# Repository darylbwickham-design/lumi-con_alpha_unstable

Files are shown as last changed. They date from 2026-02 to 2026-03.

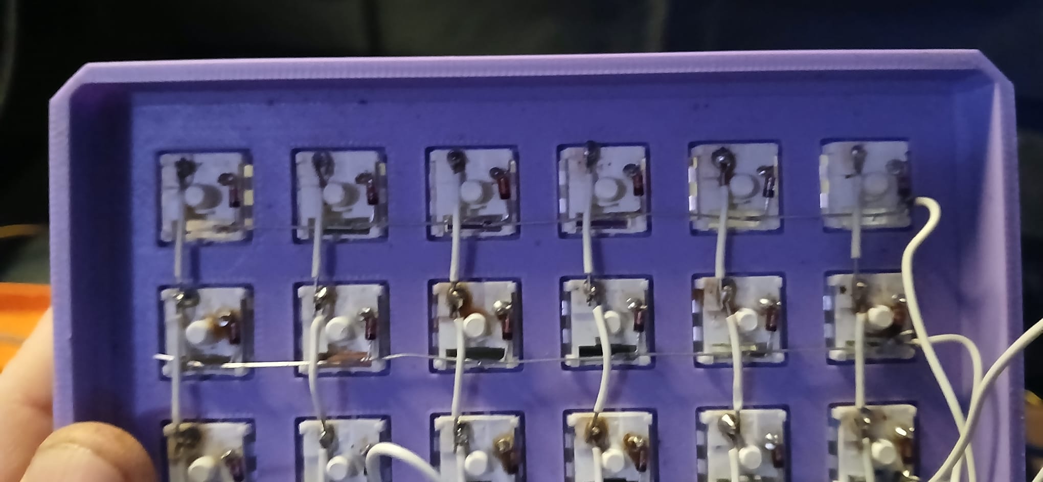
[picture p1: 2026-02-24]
Alpha/instructions/diode wiring.jpeg

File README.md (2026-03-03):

# Lumi-Con (ESP8266 + Pico) — Lumia-Based Stream Controller

Lumi-Con is an open-source, Lumia-first **control deck** built around:

- **Raspberry Pi Pico (RP2040)**: scans a key matrix (currently 6×6 test matrix)
- **ESP8266**: Wi‑Fi + HTTP + optional TFT display + relays key events to **Lumia** via a plugin

This repo/docs cover **three supported builds**:

1) **6×6 ONLY (Buttons Only)** — Pico → ESP → Lumia plugin (alerts/variations)  
2) **CHAT RELAY ONLY (TFT Chat Bridge)** — Lumia plugin → ESP TFT (display messages)  
3) **INTEGRATED (Recommended / Pro)** — same ESP firmware + integrated plugin (events + TFT actions + device status)

Important note:

- **Build 1 and Build 3 use the same ESP8266 integrated firmware.**
- Build 1 simply does **not** use TFT actions (so **ESP Base URL** can be left blank).

---

## Table of Contents

- [Hardware Overview](#hardware-overview)
- [Arduino IDE One-Time Setup](#arduino-ide-one-time-setup)
- [Wiring](#wiring)
- [Firmware Upload](#firmware-upload)
- [Plugin Build + Install (CLI)](#plugin-build--install-cli)
- [Build 1: 6×6 ONLY (Buttons Only)](#build-1-66-only-buttons-only)
- [Build 2: CHAT RELAY ONLY (TFT Chat Bridge)](#build-2-chat-relay-only-tft-chat-bridge)
- [Build 3: INTEGRATED (Recommended)](#build-3-integrated-recommended)
- [Key Labels (Short + Long)](#key-labels-short--long)
- [UI Mode: Legacy GET vs UI POST](#ui-mode-legacy-get-vs-ui-post)
- [Plugin Icon](#plugin-icon)
- [Troubleshooting](#troubleshooting)

---

## Hardware Overview

### Current test configuration

- **Pico** scans a **6×6** keypad matrix and sends packets over UART to the ESP8266.
- **ESP8266**:
  - receives UART packets on RX (GPIO3)
  - computes short/long press
  - `POST`s key events to the Lumia plugin `/event`
  - hosts TFT endpoints:
    - `GET /msg?t=...`
    - `GET /status?t=...`
    - `GET /clear`
    - `POST /ui` (optional UI JSON endpoint)
    - `GET /health` (device health JSON)

---

## Arduino IDE One-Time Setup

### 1) Install Arduino IDE

https://www.arduino.cc/en/software

### 2) Add board manager URLs

Arduino IDE → **File → Preferences** → **Additional Boards Manager URLs**  
Paste (comma-separated is fine):

- ESP8266  
  `http://arduino.esp8266.com/stable/package_esp8266com_index.json`

- Pico (Earle Philhower)  
  `https://github.com/earlephilhower/arduino-pico/releases/download/global/package_rp2040_index.json`

### 3) Install board packages

Arduino IDE → **Tools → Board → Boards Manager**  
Install:

- **ESP8266 by ESP8266 Community**
- **Raspberry Pi Pico/RP2040** (Earle Philhower)

---

## Wiring

IMPORTANT (ESP flashing):

- When uploading to the ESP8266, disconnect **Pico TX (GP0) → ESP RX (GPIO3)** or the upload may fail.

### A) Pico ↔ 6×6 Matrix (matches `6x6_test_pico.ino`)

Rows (inputs w/ pullups):

- R0 → **GP12**
- R1 → **GP1**
- R2 → **GP2**
- R3 → **GP3**
- R4 → **GP4**
- R5 → **GP5**

Cols (outputs):

- C0 → **GP6**
- C1 → **GP7**
- C2 → **GP8**
- C3 → **GP9**
- C4 → **GP10**
- C5 → **GP11**

### B) Pico → ESP8266 UART

- Pico **GP0 (TX)** → ESP **RX / GPIO3**
- Pico **GND** → ESP **GND**
- Optional but recommended: **1k resistor** in series on the TX line

### C) ESP8266 → ST7735 TFT (SPI)

Common wiring for typical ESP8266 dev boards:

- TFT **VCC**  → **3V3**
- TFT **GND**  → **GND**
- TFT **SCK**  → **D5 (GPIO14)**
- TFT **MOSI** → **D7 (GPIO13)**
- TFT **CS**   → **D2 (GPIO4)**
- TFT **DC**   → **D1 (GPIO5)**
- TFT **RST**  → **D0 (GPIO16)**

---

## Firmware Upload

### Flash the Pico (6×6 scanner)

1. Plug Pico into your PC via USB
2. Arduino IDE → select board: **Raspberry Pi Pico**
3. Open: `6x6_test_pico.ino`
4. Upload
5. Optional: Serial Monitor at **115200** to see `PRESS/RELEASE` logs

### Flash the ESP8266

1. Disconnect Pico GP0 → ESP RX (GPIO3) while uploading
2. Plug ESP8266 into PC via USB
3. Arduino IDE → select your ESP8266 board
4. Open and upload the ESP sketch you want (see builds below)
5. Reconnect Pico GP0 → ESP RX after upload

---

## Plugin Build + Install (CLI)

Open a terminal in the plugin folder (the folder containing `package.json`).

### Build (Windows)

```bash
npm install
npx lumia-plugin validate .
npx lumia-plugin build . --out .\OUTPUT_NAME.lumiaplugin
```

### Install into Lumia

- Lumia → Configuration → Plugins → Installed → Install Manually
- Select the `.lumiaplugin` you built

---

## Build 1: 6×6 ONLY (Buttons Only)

### What it does

- Pico scans keys → ESP sends events to a Lumia plugin
- Lumia plugin triggers two alerts:
  - **6×6 short**
  - **6×6 long**
- Each alert supports **36 variations** (Key `0–35`)

### Firmware used (same as Integrated)

- Pico: `6x6_test_pico.ino`
- ESP: `lumi_con_esp_integrated_0_0_4.ino` (or your current integrated firmware)

### Plugin (Lumia)

- Install: **Lumi-Con Bridge (Integrated v5.2)** (`.lumiaplugin`)
- Minimal settings (buttons only):
  - Enable Listener = **ON**
  - Listen Port = **8787**
  - Shared Secret = **(blank)**
- You can leave **ESP Base URL** blank if you are not using a TFT.

### ESP config (edit + flash)

```cpp
const char* PLUGIN_HOST = "192.168.1.87"; // your PC IP
constexpr uint16_t PLUGIN_PORT = 8787;    // same as Listen Port
const char* PLUGIN_SECRET = "";           // same as Shared Secret (or blank)
```

---

## Build 2: CHAT RELAY ONLY (TFT Chat Bridge)

### What it does

- Lumia plugin sends display text to the ESP TFT
- Uses:
  - `GET /msg?t=...`
  - `GET /clear`

### Firmware used

- ESP: `espChatBridge.ino` (hardcoded Wi‑Fi)

### ESP Wi‑Fi (edit + flash)

```cpp
const char* WIFI_SSID = "YourWiFiName";
const char* WIFI_PASS = "YourWiFiPassword";
```

### Plugin (Lumia)

- Install: `ESP8266_TFT_Chat_Bridge.lumiaplugin`
- Settings:
  - ESP Base URL = `http://<ESP_IP>`
  - Message Path = `/msg`
  - Clear Path = `/clear`

### Quick test (browser)

- `http://<ESP_IP>/msg?t=Hello%20world`
- `http://<ESP_IP>/clear`

---

## Build 3: INTEGRATED (Recommended)

### What it does

Same ESP firmware + integrated Lumia plugin:

Device → PC (plugin listener)

- `POST http://<PC_IP>:8787/event` with JSON like `{ "event": 0..71 }`

Plugin → device (TFT actions)

- Display Add Line → `/msg` (Legacy GET) or `/ui` (UI POST)
- Display Set Status → `/status` (Legacy GET) or `/ui` (UI POST)
- Display Clear → `/clear` (Legacy GET) or `/ui` (UI POST)

Integrated plugins can also add:

- device connected/offline state
- device status variables (device id, last seen, RSSI, etc.)
- optional debug toasts

### Firmware used

- Pico: `6x6_test_pico.ino`
- ESP: `lumi_con_esp_integrated_0_0_4.ino` (or your current integrated firmware)

### Plugin (Lumia)

- Install: **Lumi-Con Bridge (Integrated v5.2)** (`.lumiaplugin`)

Minimal settings:

- Enable Listener = **ON**
- Listen Port = **8787**
- Shared Secret = **(blank)**

Optional (for TFT actions):

- ESP Base URL = `http://<ESP_IP>`

Optional (if you set a secret):

- Shared Secret must match what the ESP sends.

### ESP first-time Wi‑Fi (WiFiManager)

1. Power ESP → Wi‑Fi AP appears: `Lumi-Con-Setup`
2. Connect to `Lumi-Con-Setup`
3. Open: `http://192.168.4.1`
4. Select home Wi‑Fi + password → Save
5. ESP reboots → TFT shows IP

### ESP firmware config (edit + flash)

```cpp
const char* PLUGIN_HOST = "192.168.1.87"; // your PC IP
constexpr uint16_t PLUGIN_PORT = 8787;    // same as plugin Listen Port
const char* PLUGIN_SECRET = "";           // same as plugin Shared Secret (or blank)
```

---

## Key Labels (Short + Long)

Integrated plugins that support key maps provide:

- Key labels (Short 0–35): 36 lines, one label per key
- Key labels (Long 0–35): 36 lines, one label per key

The plugin exposes `key_label` and automatically picks the correct list based on short/long press.

---

## UI Mode: Legacy GET vs UI POST

This affects **TFT display only** (not key presses).

### Legacy GET (simple)

Plugin sends:

- `GET http://<ESP_IP>/msg?t=...`
- `GET http://<ESP_IP>/status?t=...`
- `GET http://<ESP_IP>/clear`

### UI POST (JSON)

Plugin sends:

- `POST http://<ESP_IP>/ui`

Example payloads:

- `{"channel":"status","text":"..."}`
- `{"channel":"chat","text":"..."}`
- `{"channel":"clear"}`

### Quick UI POST test (Windows PowerShell)

```powershell
curl -X POST "http://<ESP_IP>/ui" -H "Content-Type: application/json" -d "{\"channel\":\"status\",\"text\":\"OK: Connected\"}"
curl -X POST "http://<ESP_IP>/ui" -H "Content-Type: application/json" -d "{\"channel\":\"chat\",\"text\":\"Hello\"}"
curl -X POST "http://<ESP_IP>/ui" -H "Content-Type: application/json" -d "{\"channel\":\"clear\"}"
```

---

## Plugin Icon

1) Put your icon file in the plugin folder (same folder as `manifest.json`)  
Recommended name: `icon.png`

2) Edit `manifest.json` (top-level, near id/name/version) and add:

```json
"icon": "./icon.png"
```

3) Rebuild:

```bash
npm install
npx lumia-plugin validate .
npx lumia-plugin build . --out .\YOUR_OUTPUT_NAME.lumiaplugin
```

Notes:

- PNG square icons work best (256×256 recommended)
- If validate fails, double-check the icon path matches the filename exactly

---

## Troubleshooting

### ESP upload fails

- Disconnect **Pico GP0 (TX) → ESP RX (GPIO3)** during ESP flashing.

### TFT is white / blank

Try these in order:

1) Change ST7735 tab in code  
`INITR_GREENTAB` → `INITR_REDTAB` or `INITR_BLACKTAB`

2) RST on D0 can be flaky  
Wire TFT RST → ESP RST and set RST pin to `-1` in the constructor if needed.

### Lumia alerts don’t fire

- Confirm ESP `PLUGIN_HOST` is your **PC IP**
- Confirm ESP `PLUGIN_PORT` matches plugin **Listen Port**
- If using Shared Secret, both ends must match exactly
- Make sure PC and ESP are on the same LAN

### TFT message actions don’t work

- Confirm plugin setting **ESP Base URL** is correct:
  - must be `http://<ESP_IP>` (no trailing slash)
- Confirm ESP endpoints work in browser:
  - `/msg?t=Hello`
  - `/status?t=OK`
  - `/clear`

### Device health endpoints

- ESP health: `http://<ESP_IP>/health`
- Plugin health (listener): `http://<PC_IP>:8787/health`

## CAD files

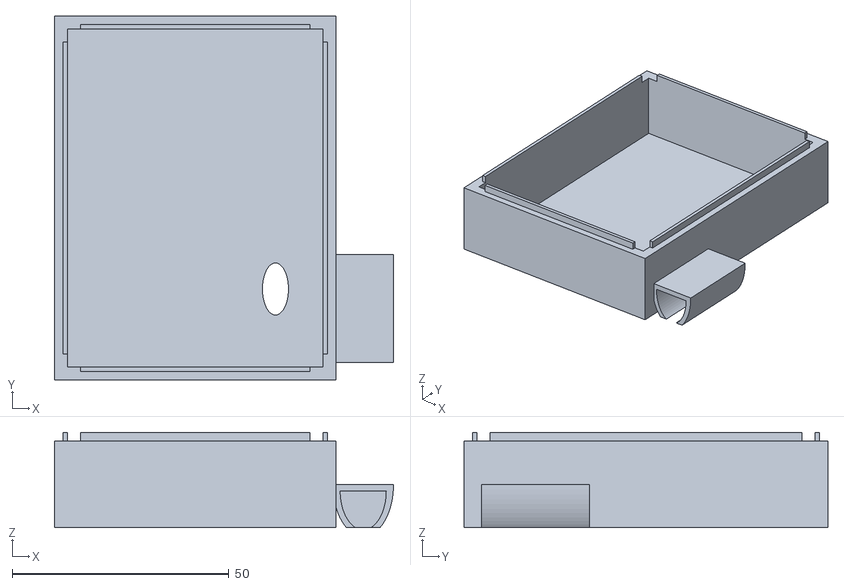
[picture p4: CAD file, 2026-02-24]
Alpha/3d files/left 3x4 rear.stl
78.2 x 84.0 x 22.0

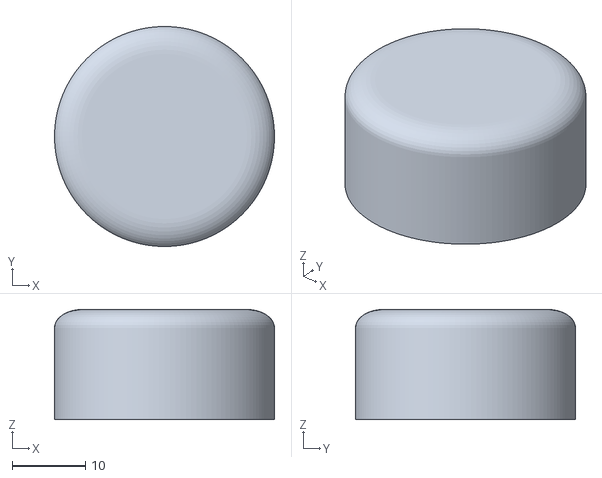
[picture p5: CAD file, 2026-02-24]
Alpha/3d files/rotary dial.stl
30.0 x 30.0 x 15.0

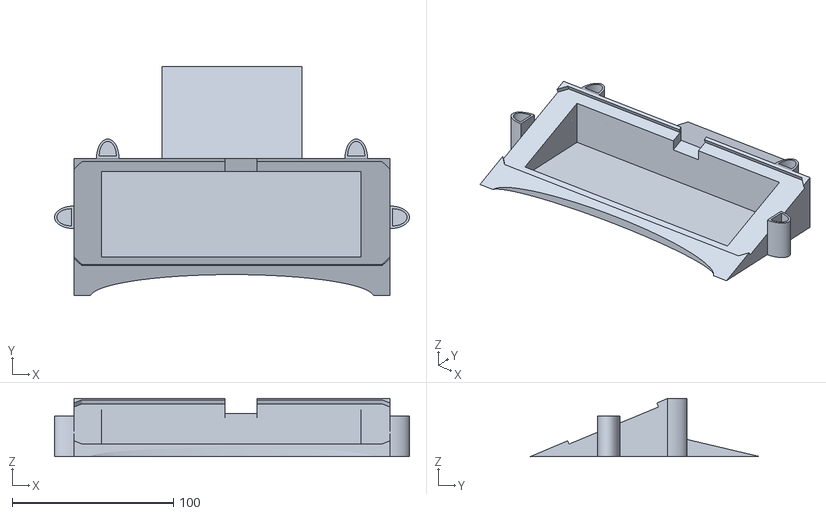
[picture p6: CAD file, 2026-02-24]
Alpha/3d files/Base.stl
220.0 x 142.0 x 36.0

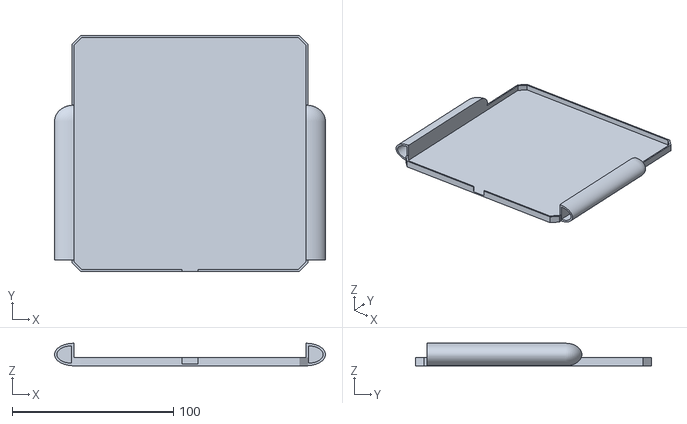
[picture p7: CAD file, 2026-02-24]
Alpha/3d files/6X6 Rear.stl
168.0 x 146.0 x 14.0

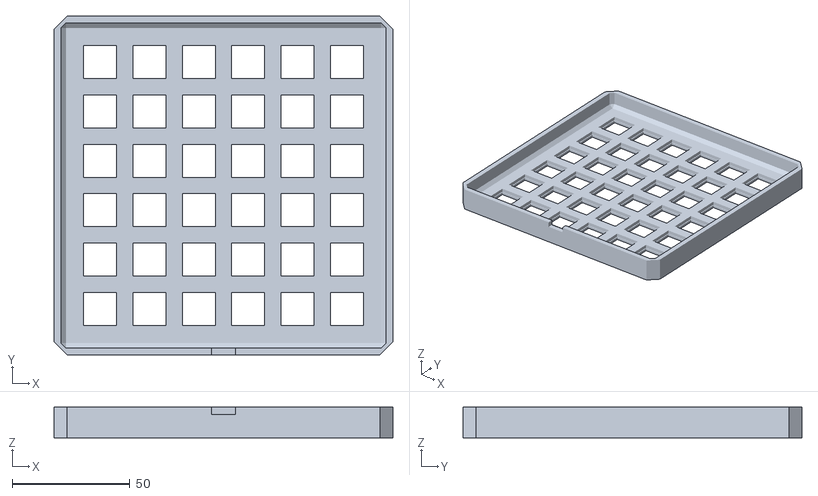
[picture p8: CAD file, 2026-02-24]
Alpha/3d files/6X6 Front.stl
144.0 x 144.0 x 13.0

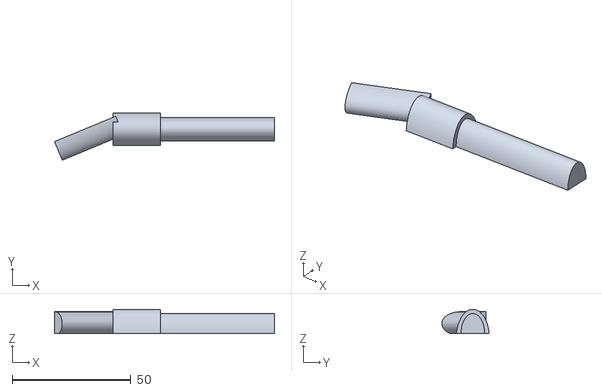
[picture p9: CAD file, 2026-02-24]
Alpha/3d files/connector.stl
92.7 x 20.0 x 10.2

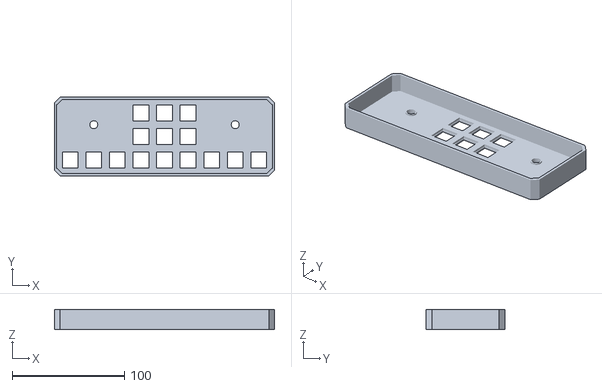
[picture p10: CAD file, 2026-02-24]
Alpha/3d files/Base Front Panel.stl
196.0 x 70.0 x 18.0

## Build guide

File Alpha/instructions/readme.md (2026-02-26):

# Lumi-Con (ESP8266 + Pico) — Lumia-Based Stream Controller

Lumi-Con is an open-source, Lumia-first “stream deck” style controller built around:
- **Raspberry Pi Pico (RP2040)**: scans a key matrix (currently 6×6 test matrix)
- **ESP8266**: Wi-Fi + HTTP + TFT display + relays key events to Lumia via a plugin

This repo/docs cover **three supported builds**:

1) **6×6 ONLY (Matrix Relay)**  
   Pico → ESP → Lumia plugin (alerts/variations)

2) **CHAT RELAY ONLY (TFT Chat Bridge)**  
   Lumia plugin → ESP TFT (display messages)

3) **INTEGRATED (Recommended)**  
   One ESP firmware + one plugin (events + TFT actions)

---

## Table of Contents
- [Hardware Overview](#hardware-overview)
- [Arduino IDE One-Time Setup](#arduino-ide-one-time-setup)
- [Wiring](#wiring)
- [Firmware Upload](#firmware-upload)
  - [Flash the Pico (6×6 scanner)](#flash-the-pico-66-scanner)
  - [Flash the ESP8266](#flash-the-esp8266)
- [Plugin Build + Install](#plugin-build--install)
- [Build 1: 6×6 ONLY (Matrix Relay)](#build-1-66-only-matrix-relay)
- [Build 2: CHAT RELAY ONLY (TFT Chat Bridge)](#build-2-chat-relay-only-tft-chat-bridge)
- [Build 3: INTEGRATED (Recommended)](#build-3-integrated-recommended)
- [Plugin Icon](#plugin-icon)
- [Troubleshooting](#troubleshooting)

---

## Hardware Overview

### Current test configuration
- **Pico** scans a **6×6** keypad matrix and sends packets over UART to the ESP8266.
- **ESP8266**:
  - receives UART packets on RX
  - computes short/long press
  - `POST`s key events to the Lumia plugin `/event`
  - hosts TFT endpoints:
    - `GET /msg?t=...`
    - `GET /status?t=...`
    - `GET /clear`
    - optional: `POST /ui` (future UI hook)

---

## Arduino IDE One-Time Setup

### 1) Install Arduino IDE
https://www.arduino.cc/en/software

### 2) Add board manager URLs
Arduino IDE → **File → Preferences** → **Additional Boards Manager URLs**  
Paste (comma-separated is fine):

- ESP8266:
  - `http://arduino.esp8266.com/stable/package_esp8266com_index.json`
- Pico (Earle Philhower):
  - `https://github.com/earlephilhower/arduino-pico/releases/download/global/package_rp2040_index.json`

### 3) Install board packages
Arduino IDE → **Tools → Board → Boards Manager**  
Install:
- **ESP8266 by ESP8266 Community**
- **Raspberry Pi Pico/RP2040** (Earle Philhower)

---

## Wiring

> **IMPORTANT (ESP flashing):** When uploading to the ESP8266, disconnect **Pico TX (GP0) → ESP RX (GPIO3)** or the upload may fail.

### A) Pico ↔ 6×6 Matrix (matches `6x6_test_pico.ino`)
**Rows** (inputs w/ pullups):
- R0 → **GP12**
- R1 → **GP1**
- R2 → **GP2**
- R3 → **GP3**
- R4 → **GP4**
- R5 → **GP5**

**Cols** (outputs):
- C0 → **GP6**
- C1 → **GP7**
- C2 → **GP8**
- C3 → **GP9**
- C4 → **GP10**
- C5 → **GP11**

### B) Pico → ESP8266 UART
- Pico **GP0 (TX)** → ESP **RX / GPIO3**
- Pico **GND** → ESP **GND**
- (Optional but recommended) **1k resistor** in series on the TX line

### C) ESP8266 → ST7735 TFT (SPI)
Common wiring for NodeMCU / Wemos D1 mini style ESP8266:

- TFT **VCC**  → **3V3**
- TFT **GND**  → **GND**
- TFT **SCK**  → **D5 (GPIO14)**
- TFT **MOSI** → **D7 (GPIO13)**
- TFT **CS**   → **D2 (GPIO4)**
- TFT **DC**   → **D1 (GPIO5)**
- TFT **RST**  → **D0 (GPIO16)**

**If the TFT is white:** see [Troubleshooting](#troubleshooting).

---

## Firmware Upload

### Flash the Pico (6×6 scanner)
1. Plug Pico into your PC via USB
2. Arduino IDE → select board: **Raspberry Pi Pico**
3. Open: `6x6_test_pico.ino`
4. Upload
5. Optional: Serial Monitor at **115200** to see `PRESS/RELEASE` logs

### Flash the ESP8266
1. **Disconnect** Pico GP0 → ESP RX (GPIO3) while uploading
2. Plug ESP8266 into PC via USB
3. Arduino IDE → select your ESP8266 board (NodeMCU / Wemos D1 mini / etc.)
4. Open and upload the ESP sketch you want (see build sections below)
5. Reconnect Pico GP0 → ESP RX after upload

---

## Plugin Build + Install

### Build (CLI)
Open a terminal in the plugin folder (the folder containing `package.json`):

```bash
npm install
npx lumia-plugin validate .
npx lumia-plugin build . --out .\OUTPUT_NAME.lumiaplugin

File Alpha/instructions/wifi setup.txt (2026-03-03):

============================================================
LUMI-CON SETUP NOTES (COPY/PASTE)
============================================================

-----------------------------
1) 6x6 ONLY (Buttons Only)
-----------------------------

LUMIA (PC) - PLUGIN SETTINGS
- Install/Enable plugin: Lumi-Con Bridge (Integrated v5.2)
- Enable Listener: ON
- Listen Port: 8787
- Shared Secret: (leave blank) OR set a value
- ESP Base URL: (leave blank if you are not using a TFT)

ESP (DEVICE) - FIRMWARE SETTINGS (edit + flash)
Set these to match Lumia plugin + your PC IP:

const char* PLUGIN_HOST = "192.168.1.87"; // your PC IP
constexpr uint16_t PLUGIN_PORT = 8787;    // same as Listen Port
const char* PLUGIN_SECRET = "";           // same as Shared Secret (or blank)

WHAT SHOULD HAPPEN
- Press keys -> ESP POSTs to: http://PC_IP:8787/event
- Lumia triggers short/long alerts with variations

-----------------------------
2) CHAT RELAY ONLY (TFT Chat Bridge)
-----------------------------

ESP (DEVICE) - WIFI SETUP (hardcoded sketch: espChatBridge.ino)
Edit + flash:

const char* WIFI_SSID = "YourWiFiName";
const char* WIFI_PASS = "YourWiFiPassword";

LUMIA (PC) - PLUGIN SETTINGS
- Install/Enable plugin: ESP8266_TFT_Chat_Bridge
- ESP Base URL: http://<ESP_IP>     (ESP IP shows on TFT)
- Message Path: /msg
- Clear Path: /clear

QUICK TEST (browser)
- http://<ESP_IP>/msg?t=Hello%20world
- http://<ESP_IP>/clear

-----------------------------
3) INTEGRATED (Buttons + TFT)

NOTE: Build 1 and Build 3 use the same ESP8266 integrated firmware.
-----------------------------

ESP (DEVICE) - FIRST TIME WIFI (WiFiManager build)
1) Power ESP -> it creates Wi-Fi AP: Lumi-Con-Setup
2) Connect phone/PC to Lumi-Con-Setup
3) Open: http://192.168.4.1
4) Select home Wi-Fi + enter password -> Save
5) ESP reboots -> TFT shows: IP: x.x.x.x

LUMIA (PC) - PLUGIN SETTINGS (INTEGRATED PLUGIN)
- Install/Enable plugin: Lumi-Con Bridge (Integrated v5.2)
- Enable Listener: ON
- Listen Port: 8787
- Shared Secret: (leave blank) OR set a value
- ESP Base URL: http://<ESP_IP>
- UI Mode: legacy_get  (recommended)

ESP (DEVICE) - FIRMWARE SETTINGS (edit + flash)
Set these to match Lumia plugin + your PC IP:

const char* PLUGIN_HOST = "192.168.1.87"; // your PC IP
constexpr uint16_t PLUGIN_PORT = 8787;    // same as Listen Port
const char* PLUGIN_SECRET = "";           // same as Shared Secret (or blank)

ENDPOINTS USED (FYI)
- Events (ESP -> PC plugin): POST http://<PC_IP>:8787/event   body: {"event":0..71}
- Screen (plugin -> ESP):
  - GET http://<ESP_IP>/msg?t=...
  - GET http://<ESP_IP>/status?t=...
  - GET http://<ESP_IP>/clear

WHAT SHOULD HAPPEN
- Press keys -> Lumia alerts trigger (same as old 6x6 plugin)
- Plugin actions can send text to the TFT (/msg, /status, /clear)

============================================================

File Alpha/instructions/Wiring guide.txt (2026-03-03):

LUMI-CON WIRING GUIDE (Quick Reference)

The wiring below is for the integrated build, but it also works for “6×6 only”.
- If building **Chat Bridge only**, leave out all references to the Pico.
- If building **6×6 only**, leave out all references to the TFT screen.
If in doubt, refer to the `.ino` files.

PARTS
-----
- ESP8266 (NodeMCU / Wemos D1 mini style)
- Raspberry Pi Pico (RP2040)
- 6x6 keyboard matrix (12 wires: R0..R5, C0..C5)
- ST7735 1.8" TFT (SPI)

1) PICO <-> 6x6 MATRIX (matches pico sketch)
-----------------------------------

SEE INCLUDED IMAGES FOR DIODE WIRING

MATRIX ROWS -> PICO (INPUT_PULLUP)
R0 -> GP12
R1 -> GP1
R2 -> GP2
R3 -> GP3
R4 -> GP4
R5 -> GP5

MATRIX COLS -> PICO (OUTPUT)
C0 -> GP6
C1 -> GP7
C2 -> GP8
C3 -> GP9
C4 -> GP10
C5 -> GP11

2) PICO -> ESP8266 (UART link)
-----------------------------------

Pico GP0 (UART TX) -> ESP RX / GPIO3
Pico GND           -> ESP GND

(Optional, recommended: 1k resistor in series on the TX line)

3) ESP8266 <-> ST7735 TFT (matches esp sketch)
-----------------------------------

TFT VCC -> ESP 3V3
TFT GND -> ESP GND

TFT SCK/SCL/CLK -> ESP D5 (GPIO14)
TFT MOSI/SDA/DIN -> ESP D7 (GPIO13)

TFT CS  -> ESP D2 (GPIO4)
TFT DC  -> ESP D1 (GPIO5)
TFT RST -> ESP D0 (GPIO16)

NOTES (if TFT shows white screen)
---------------------------------
- Try a different ST7735 tab constant in code:
  INITR_GREENTAB / INITR_REDTAB / INITR_BLACKTAB
- If RST on D0 is flaky:
  Wire TFT RST -> ESP RST and set TFT_RST = -1 in code.

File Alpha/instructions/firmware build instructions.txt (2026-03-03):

========================================
Lumi-Con Plugin Build Commands
========================================

PREREQS (one-time)
- Install Node.js (LTS)
- Open a terminal in the plugin folder (the folder containing package.json)

----------------------------------------
A) INTEGRATED v5.2 (used for 6×6 ONLY and INTEGRATED)
----------------------------------------

cd <PATH_TO_PLUGIN_FOLDER>
npm install
npx lumia-plugin validate .
npx lumia-plugin build . --out .\lumi_con_bridge_integrated_v5_2.lumiaplugin

----------------------------------------
B) TFT CHAT ONLY (ESP8266_TFT_Chat_Bridge)
----------------------------------------

cd <PATH_TO_PLUGIN_FOLDER>
npm install
npx lumia-plugin validate .
npx lumia-plugin build . --out .\ESP8266_TFT_Chat_Bridge.lumiaplugin

----------------------------------------
C) (Same as A)

Use the same integrated plugin build for both “6×6 only” and “Integrated”.
----------------------------------------

cd <PATH_TO_PLUGIN_FOLDER>
npm install
npx lumia-plugin validate .
npx lumia-plugin build . --out .\lumi_con_bridge_integrated_v5_2.lumiaplugin

----------------------------------------
NOTES
----------------------------------------
- <PATH_TO_PLUGIN_FOLDER> is the folder containing manifest.json + main.js + package.json.
- Output filename can be anything, but keep it ending in .lumiaplugin.
- After building, install in Lumia: Configuration -> Plugins -> Install Manually (select the .lumiaplugin).
========================================

========================================
Linux/Mac OS users
========================================

npx lumia-plugin build . --out ./lumi_con_bridge_integrated_v5_2.lumiaplugin
npx lumia-plugin build . --out ./ESP8266_TFT_Chat_Bridge.lumiaplugin
npx lumia-plugin build . --out ./lumi_con_bridge_integrated_v5_2.lumiaplugin

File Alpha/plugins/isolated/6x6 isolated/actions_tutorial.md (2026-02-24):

---
## Matrix Relay (6x6 Ver) — Actions / Variations

This plugin does not add manual actions.

Instead, configure actions on **Alert Variations**:

### Alerts created by this plugin
- **6x6 short**
- **6x6 long**

Each alert has a variation condition:
- **Which Key (0–35)**

### How to set it up in Lumia
1) Go to **Alerts → Matrix Relay (6x6 Ver) → 6x6 short**
2) Enable **Only Variations** (base alert is disabled by the plugin)
3) Click **Add Variation**
   - Condition: *Which Key (0–35)*
   - Value: pick *Key 0* (or whatever key you want)
4) Add the Lumia actions you want for that key
5) Repeat for Key 1..Key 35
6) Do the same for **6x6 long**

### Notes
- Short press triggers **6x6 short**
- Long press triggers **6x6 long**
- The variation matching uses `dynamic.value` (string) internally, so Key values are matched as text ("0".."35").
---

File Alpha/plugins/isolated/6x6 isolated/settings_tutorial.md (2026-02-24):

---
## Matrix Relay (6x6 Ver) — Settings

### 1) Listen Port
- Default is **8787**
- Your ESP8266 should POST to:

`http://<PC-IP>:<PORT>/event`

Example (with your IP):
`http://192.168.1.87:8787/event`

### 2) Shared Secret (optional)
If you set a secret here, your ESP8266 must include this HTTP header:

`X-Matrix-Secret: <your secret>`

### 3) Data format
The plugin expects JSON:

`{ "event": N }`

Where:
- Short press: **0..35**
- Long press: **36..71**

The plugin converts these into:
- **6x6 short** with key **0..35**
- **6x6 long** with key **0..35**
---

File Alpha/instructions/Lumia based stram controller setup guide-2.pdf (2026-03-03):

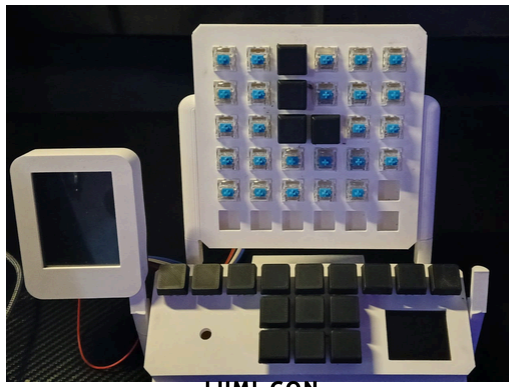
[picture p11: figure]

L U M I -C O N

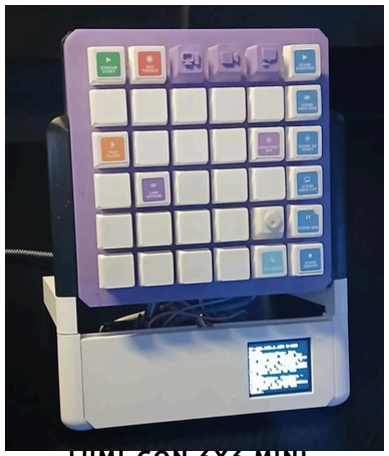
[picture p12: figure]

L U M I -C O N 6 X 6 M I N I

# L U M I A B A S E D ST R A M C O NT R O L L E R S E T U P G U I D E

### PA RT S R E Q U I R E D

- E S P 8 2 6 6
- R A S P B E R RY P I P IC O
- 3 6 × 1 N 4 1 4 8 D I O D E S
- 3 6 × M E C H A N IC A L SWITC H E S
- 1 . 8 " R G B T FT ST 7 7 3 5 ( O N LY I F Y O U WA NT C H AT /SC R E E N F E AT U R E S )

### F I L E S R E Q U I R E D

E S P 8 2 6 6 | F I R MWA R E | ( I NT E G R AT E D
F I R MWA R E ) :
- L U M I _C O N _ E S P _ I NT E G R AT E D _ 0 _ 0 _ 4

P IC O F I R MWA R E ( 6 × 6 SC A N N E R ) :
- 6 X 6 _T E ST _ P IC O

L U M I A P L U G I N ( P IC K O N E )
A ) J U ST C H AT (SC R E E N O N LY )
- E S P 8 2 6 6 -T FT -C H AT - B R I D G E B ) J U ST 6 × 6 ( B UT T O N S O N LY )
- P L U G I N V E R S I O N 5 . 2
C ) B O T H ( B UT T O N S + SC R E E N )
- P L U G I N V E R S I O N 5 . 2

# O V E R V I EW:

### WH AT T H IS IS

T H IS G U I D E C O V E R S S E T T I N G U P A L U M I -C O N C O NT R O L L E R U S I N G :
- E S P 8 2 6 6 (WI - F I + L U M I A + O PT I O N A L T FT SC R E E N )
- R A S P B E R RY P I P IC O (SC A N S T H E 6 × 6 K E Y PA D M AT R I X )
- O PT I O N A L : 1 . 8 " ST 7 7 3 5 T FT SC R E E N F O R C H AT /STAT U S D IS P L AY

## I M P O RTA NT : P IC K Y O U R P L U G I N N OW. IT C H A N G E S WH AT ST E PS

Y O U N E E D L AT E R .

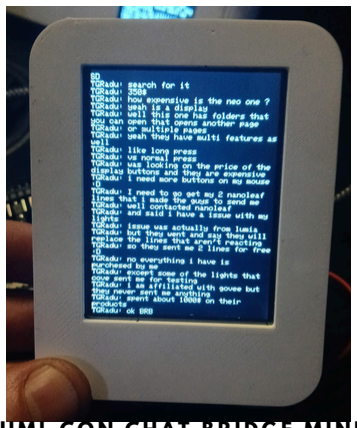
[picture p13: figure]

L U M I -C O N C H AT B R I D G E M I N I

ST E P 1 : I N STA L L A R D U I N O I D E
D OWN L O A D A R D U I N O I D E F R O M A R D U I N O ’ S WE BS IT E A N D O P E N IT.

ST E P 2 : A D D B O A R D M A N A G E R U R L S
A R D U I N O I D E → | F I L E → | P R E F E R E N C E S
A D D T H E U R L (S ) F R O M Y O U R “ B O A R D M A N A G E R U R L ” T E XT F I L E I NT O
“ A D D IT I O N A L B O A R D S M A N A G E R U R L S ”

ST E P 3 : I N STA L L B O A R D PAC K A G E S
A R D U I N O I D E → | T O O L S → | B O A R D →
B O A R D S M A N A G E R
I N STA L L :
- R A S P B E R RY P I P IC O / R P 2 0 4 0 B O A R D PAC K A G E
- E S P 8 2 6 6 B O A R D PAC K A G E

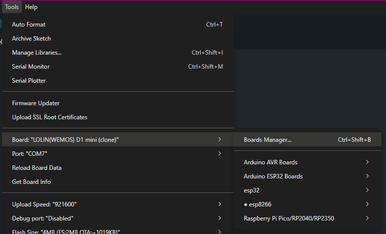
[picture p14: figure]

ST E P 4 : F L A S H T H E P IC O ( 6 × 6 SC A N N E R )
1 . P L U G T H E P IC O I NT O Y O U R PC WIT H U S B 2 . O P E N T H E 6 X 6 _T E ST _ P IC O S K E TC H I N
A R D U I N O I D E
3 . C L IC K U P L O A D
4 . O P E N S E R I A L M O N IT O R
5 . P R E SS K E YS O N Y O U R K E Y PA D
6 . Y O U S H O U L D S E E C O N F I R M AT I O N
M E SS A G E S A P P E A R I N S E R I A L M O N IT O R .

ST E P 5 : F L A S H T H E E S P 8 2 6 6 (WI - F I + L U M I A + O PT I O N A L T FT )
I M P O RTA NT : D U R I N G E S P F L A S H I N G ,
D ISC O N N E C T T H E E S P R X P I N F R O M T H E
P IC O .
( I F R X IS C O N N E C T E D , U P L O A D I N G C A N FA I L . )
1 . P L U G E S P 8 2 6 6 I NT O U S B
2 . O P E N L U M I _C O N _ E S P _ I NT E G R AT E D I N
A R D U I N O I D E
3 . C L IC K U P L O A D
4 . WH E N T H E E S P S UC C E SS F U L LY R E C E IV E S A B UT T O N P R E SS , T H E E S P ’ S O N - B O A R D L E D S H O U L D F L A S H .
A FT E R F L A S H I N G IS C O M P L E T E : R E C O N N E C T T H E P IC O → E S P R X WI R E I F Y O U A R E U S I N G T H E 6 × 6 B UT T O N S .

# F I R MWA R E F L A S H I N G :

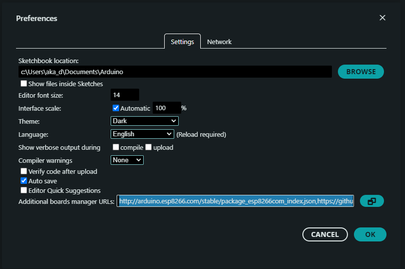
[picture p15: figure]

S T E P 2

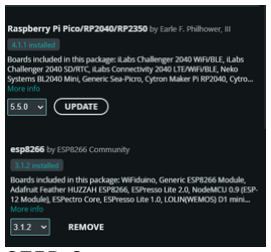
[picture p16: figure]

S T E P 3

ST E P 3

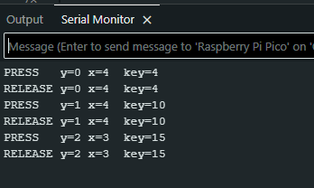
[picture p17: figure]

P IC O E X P E C T E D S E R I A L O UT P UT

ST E P 1 : C R E AT E A P L U G I N B U I L D F O L D E R
1 . M A K E A N EW F O L D E R A NYWH E R E
( D E S KT O P IS F I N E )
2 . N A M E IT S O M E T H I N G O BV I O U S ( E X A M P L E : L U M I _ P L U G I N _ B U I L D )
3 . C O PY T H E P L U G I N F I L E S Y O U WA NT T O
U S E I NT O T H IS F O L D E R

ST E P 2 : O P E N C O M M A N D P R O M PT I N T H AT F O L D E R
I N F I L E E X P L O R E R , C L IC K T H E A D D R E SS
B A R , T Y P E :
C M D
P R E SS E NT E R . A C O M M A N D P R O M PT O P E N S I N T H AT F O L D E R .

ST E P 3 : B U I L D T H E P L U G I N
R U N T H E S E C O M M A N D S :

N P M I N STA L L
N P X L U M I A - P L U G I N VA L I D AT E .
N P X L U M I A - P L U G I N B U I L D . - - O UT .
\ L U M I _C O N _ B R I D G E _ I NT E G R AT E D _V 5 _ 2 . L U M I A P L U G I N

R E N A M E
“ L U M I _C O N _ B R I D G E _ I NT E G R AT E D _V 5 _ 2 ” T O WH AT E V E R Y O U WA NT T H E O UT P UT F I L E T O B E C A L L E D .

ST E P 4 : I N STA L L I NT O L U M I A
I N L U M I A :
C O N F I G U R AT I O N → | P L U G I N S → | I N STA L L E D
→ | I N STA L L M A N U A L LY
D R A G I N ( O R S E L E C T ) T H E . L U M I A P L U G I N F I L E Y O U J U ST C R E AT E D .

# P L U G I N B U I L D A N D I N S T A L L

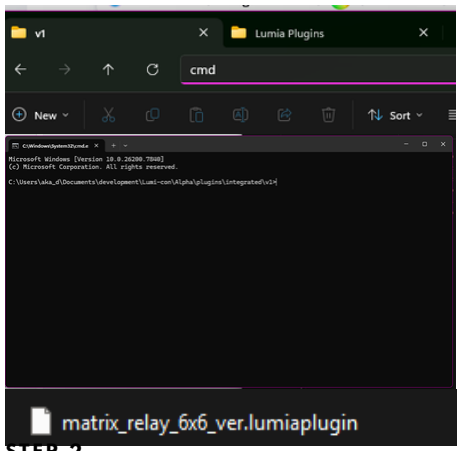
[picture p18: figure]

ST E P 2

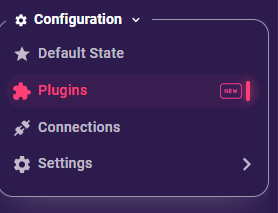
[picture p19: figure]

ST E P 4

ST E P 4

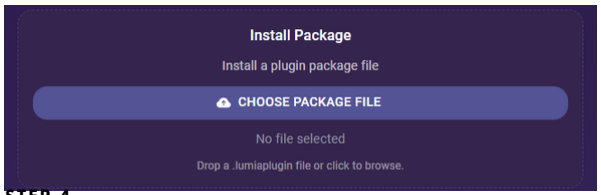
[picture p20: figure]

ST E P 4

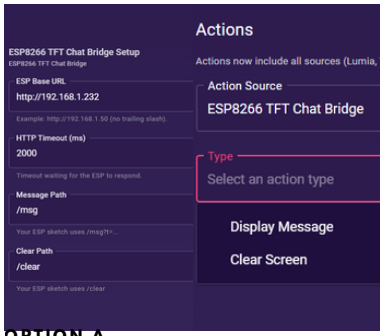
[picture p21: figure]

O PT I O N A

### A ) I F Y O U C H O S E “ J U ST C H AT ” ( E S P 8 2 6 6 -T FT -C H AT - B R I D G E )

1 . O P E N T H E P L U G I N ’ S S E T T I N G S I N L U M I A . 2 . A FT E R WI - F I C O N N E C T S , Y O U R E S P 8 2 6 6 WI L L S H OW IT S I P A D D R E SS O N T H E T FT. 3 . E NT E R T H AT I P A D D R E SS I NT O T H E
P L U G I N ’ S “ E S P B A S E U R L ” / “ D E V IC E I P ” F I E L D (WH IC H E V E R Y O U R P L U G I N
S H OWS ) .
4 . C L IC K S AV E .
5 . Y O U S H O U L D N OW S E E T H E D IS P L AY
AC T I O N S ( F O R E X A M P L E : A D D L I N E / S E T STAT U S / C L E A R ) , A N D L U M I A S H O U L D B E A B L E T O U P D AT E T H E SC R E E N .

### B ) I F Y O U C H O S E “ J U ST 6 × 6 ” ( 6 X 6 IS O L AT E D )

1 . O P E N T H E P L U G I N ’ S S E T T I N G S I N L U M I A . 2 . C L IC K S AV E .
3 . Y O U S H O U L D N OW S E E T H E 6 × 6 A L E RT S A P P E A R (T Y P IC A L LY “ 6 × 6 S H O RT ” A N D “ 6 × 6 L O N G ” ) .
4 . U S E VA R I AT I O N S ( K E Y 0 – 3 5 ) T O S E T
D I F F E R E NT AC T I O N S P E R B UT T O N .

### C ) I F Y O U C H O S E “ B O T H ” ( L U M I -C O N B R I D G E I NT E G R AT E D V 5 . 2 )

1 . O P E N T H E I NT E G R AT E D P L U G I N ’ S
S E T T I N G S I N L U M I A .
2 . M A K E S U R E “ E N A B L E L IST E N E R ” IS O N
(T H IS R E C E IV E S B UT T O N E V E NT S ) .
3 . E NT E R T H E E S P 8 2 6 6 I P A D D R E SS (S H OWN O N T H E T FT A FT E R WI - F I C O N N E C T S ) I NT O “ E S P B A S E U R L ” (T H IS E N A B L E S SC R E E N AC T I O N S ) .
4 . C L IC K S AV E .
5 . Y O U S H O U L D N OW S E E :
6 . • A L E RT S : 6 × 6 S H O RT + 6 × 6 L O N G ( F O R B UT T O N S )
7 . • AC T I O N S : D IS P L AY A D D L I N E /
D IS P L AY S E T STAT U S / D IS P L AY C L E A R
( F O R T FT )

### F I N A L C H E C K ( A L L B U I L D S )

A FT E R Y O U C L IC K S AV E :
- A L E RT S A N D / O R AC T I O N S S H O U L D
A P P E A R I N L U M I A F O R Y O U R C H O S E N
P L U G I N .
I F N O T H I N G A P P E A R S : D O U B L E C H E C K Y O U I N STA L L E D T H E C O R R E C T P L U G I N , T H E N
R E O P E N T H E P L U G I N S E T T I N G S A N D C L IC K S AV E A G A I N .

# P L U G I N C O N F I G

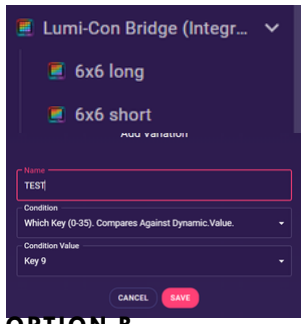
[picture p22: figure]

O PT I O N B

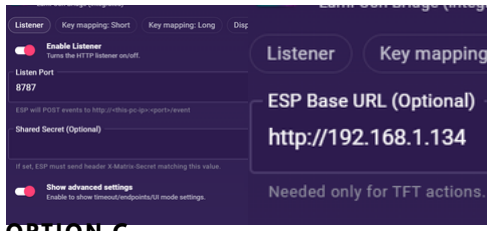
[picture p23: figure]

O PT I O N C

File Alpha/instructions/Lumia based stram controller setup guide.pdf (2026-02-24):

# L U M I A B A S E D ST R A M C O NT R O L L E R S E T U P G U I D E

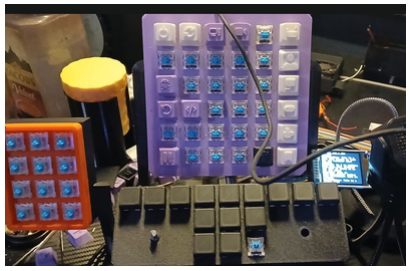
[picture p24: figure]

## PA RT S R E Q U I R E D :

E S P 8 2 6 6
P IC O P I
3 6 O F 1 N 4 1 4 8 S I G N A L D I O D E S 3 6 O F M E C H A N IC L K E YS
1 . 8 " R G B L C D T FT ST 7 7 3 5

## F I L E S R E Q U I R E D :

E S P 8 2 6 6 :
L U M I _C O N _ E S P _ I N E T R A G E D _ 0 _ 0 _ 1 P IC O P I :

### 6 X 6 _T E ST _ P IC O

L U M I A ( P IC K O N E ) :

F O R J U ST C H AT ;
E S P 8 2 6 6 -T FT -C H AT - B R I D G E

F O R J U ST 6 X 6 ;

### 6 X 6 IS O L AT E D

F O R B O T H ;
L U M I _C O N _ E S P _ I N E T R A G E D _ 0 _ 0 _ 1

# I NT R O D UC T I O N

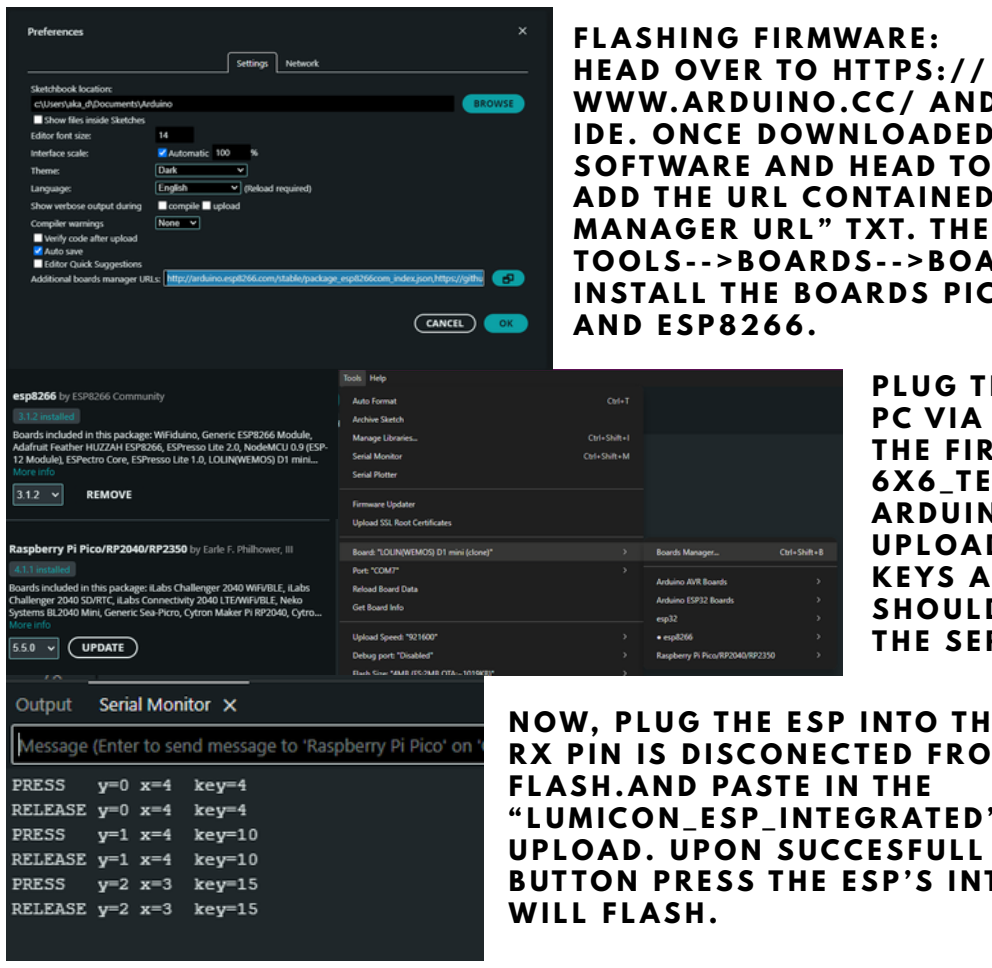
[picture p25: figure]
F L A S H I N G F I R MWA R E : H E A D O V E R T O HT T PS : / /

WWW. A R D U I N O .C C / A N D D OWN L O A D T H E I D E . O N C E D OWN L O A D E D O P E N T H E
S O FTWA R E A N D H E A D T O P R E F E R E N C E S A N D A D D T H E U R L C O NTA I N E D I N T H E “ B O A R D
M A N A G E R U R L ” T XT. T H E N P R O C E E D T O
T O O L S - - > B O A R D S - - > B O A R D M A N A G E R .
I N STA L L T H E B O A R D S P IC T U R E D ( P IC O P I

P L U G T H E P IC O I NT O T H E PC V I A U S B C A B L E , PA ST E T H E F I R MWA R E L A B E L L E D

### 6 X 6 _T E ST _ P IC O I NT O

A R D U I N O A N D C L IC K
U P L O A D , U P O N P R E SS I N G K E YS A C O N F R I M AT I O N
S H O U L D B E S E NT B AC K V I A T H E S E R I A L M O N IT O R .

N OW, P L U G T H E E S P I NT O T H E U S B , E N S U R E T H E R X P I N IS D ISC O N E C T E D F R O M T H E P IC O D U R I N G

“ L U M IC O N _ E S P _ I NT E G R AT E D ” I NT O T H E I D E . H IT U P L O A D . U P O N S UC C E S F U L L R E C I E PT O F A
B UT T O N P R E SS T H E E S P ’ S I NT E G E G R AT E D L E D

# F I R MWA R E

# P L U G I N

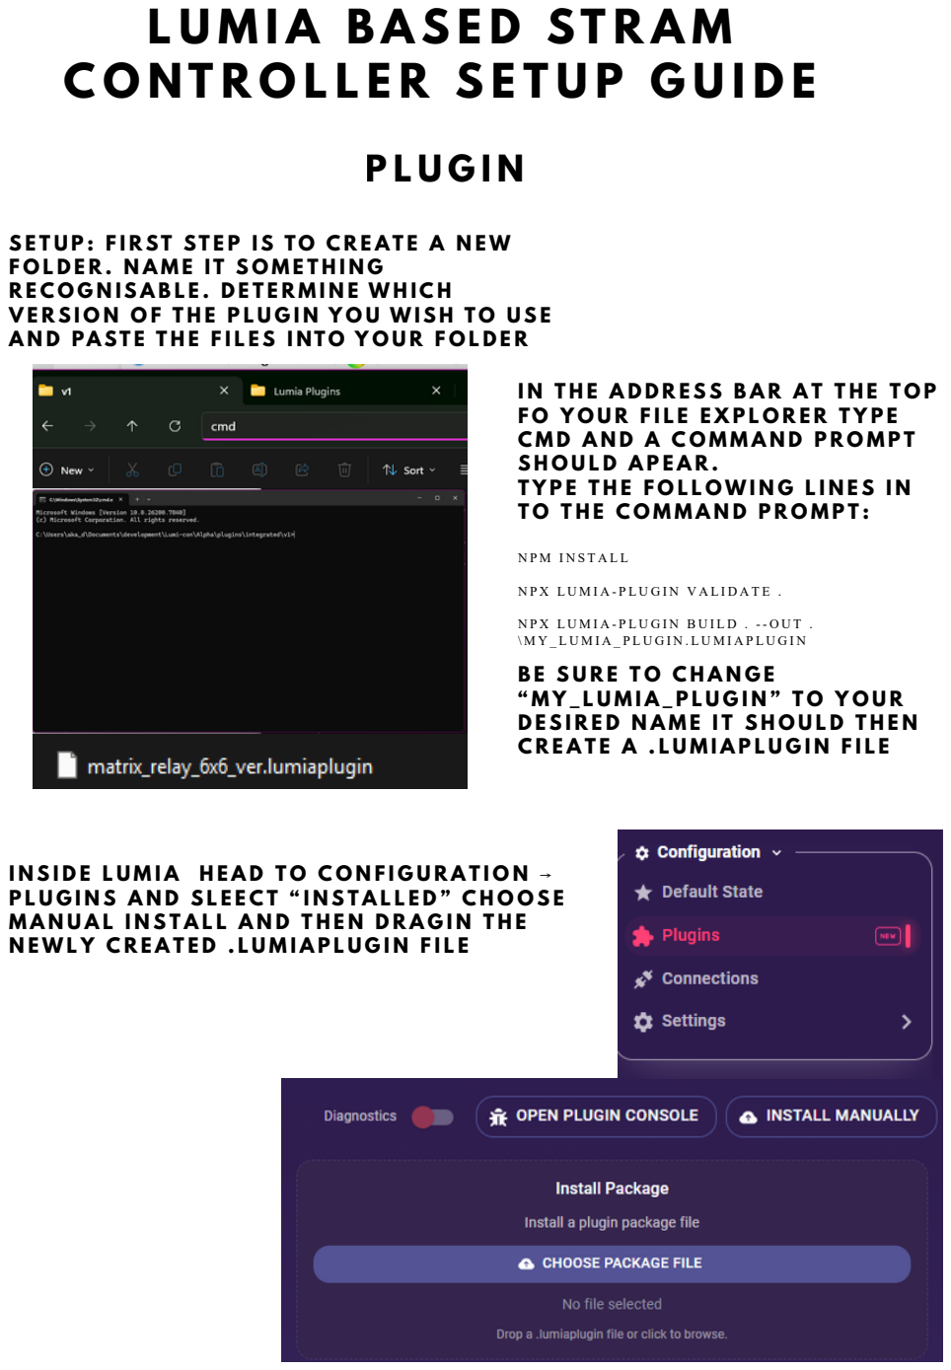
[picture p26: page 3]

S E T U P : F I R ST ST E P IS T O C R E AT E A N EW
F O L D E R . N A M E IT S O M E T H I N G
R E C O G N IS A B L E . D E T E R M I N E WH IC H
V E R S I O N O F T H E P L U G I N Y O U WIS H T O U S E A N D PA ST E T H E F I L E S I NT O Y O U R F O L D E R

I N T H E A D D R E S S B A R A T T H E T O P F O Y O U R F I L E E X P L O R E R T Y P E
C M D A N D A C O M M A N D P R O M P T S H O U L D A P E A R .
T Y P E T H E F O L L OWI N G L I N E S I N T O T H E C O M M A N D P R O M P T :

N P M I N S T A L L

N P X L U M I A - P L U G I N V A L I D A T E .

N P X L U M I A - P L U G I N B U I L D . - - O U T .
\ M Y _ L U M I A _ P L U G I N . L U M I A P L U G I N
B E S U R E T O C H A N G E
“ M Y _ L U M I A _ P L U G I N ” T O Y O U R D E S I R E D N A M E I T S H O U L D T H E N C R E A T E A . L U M I A P L U G I N F I L E

I N S I D E L U M I A H E A D T O C O N F I G U R A T I O N ⟶ P L U G I N S A N D S L E E C T “ I N S T A L L E D ” C H O O S E M A N U A L I N S T A L L A N D T H E N D R A G I N T H E
N EWL Y C R E A T E D . L U M I A P L U G I N F I L E

# P L U G I N

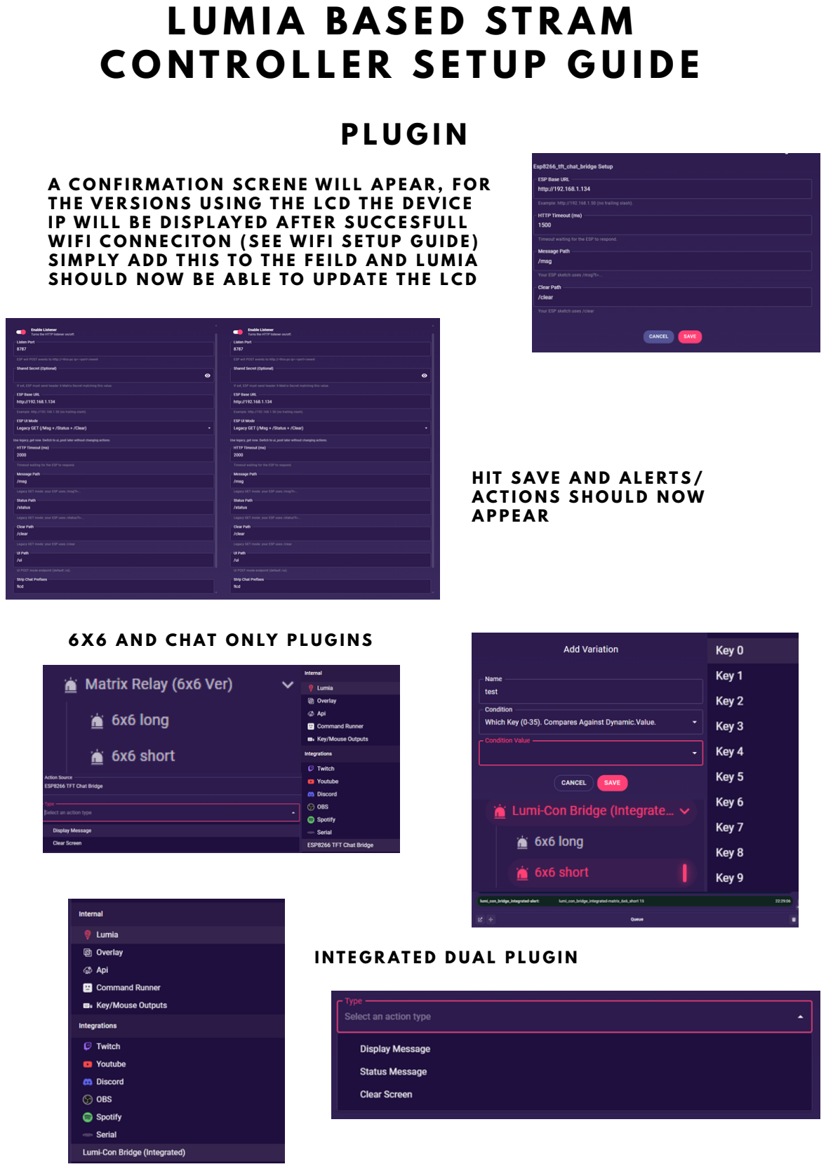
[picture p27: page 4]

A C O N F I R M AT I O N SC R E N E WI L L A P E A R , F O R T H E V E R S I O N S U S I N G T H E L C D T H E D E V IC E I P WI L L B E D IS P L AY E D A FT E R S UC C E S F U L L WI F I C O N N E C IT O N (S E E WI F I S E T U P G U I D E ) S I M P LY A D D T H IS T O T H E F E I L D A N D L U M I A S H O U L D N OW B E A B L E T O U P D AT E T H E L C D

H IT S AV E A N D A L E RT S / AC T I O N S S H O U L D N OW A P P E A R

### 6 X 6 A N D C H AT O N LY P L U G I N S

I NT E G R AT E D D U A L P L U G I N

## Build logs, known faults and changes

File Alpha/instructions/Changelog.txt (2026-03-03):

# Changelog — Lumi-Con Lumia Plugin (Integrated)
> Note: If you are using **v5.2**, it includes all v5.1 features. Any v5.2 changes are typically maintenance/packaging tweaks; check the release tag for exact details.

This changelog tracks the evolution of the **integrated Lumi-Con Lumia plugin** from **v1.0.0 → v5.1** (feature history).

Legend:
- ✅ Added
- 🔁 Changed
- 🛠 Fixed
- ⚠️ Compatibility note

---

## v5.2 (Seq Dedupe Fix) — Current
🛠 Fixed
- Fixes **seq de-duplication after a device reboot** (prevents legitimate events being ignored after restart).

✅ Includes
- All **v5.1** features (debug toasts, offline detection/status variables, TFT actions).

---

## v5.1 (Debug Toasts) — Feature Highlight
✅ **Optional debug toasts**
- Adds settings to enable/disable toasts (default OFF).
- Toast modes:
  - **Important**: device connect + device offline only
  - **Verbose**: toasts for connect/offline + every key event + every TFT action
- Includes toast throttling to reduce spam when keys are pressed rapidly.

🔁 **Professional UX**
- Keeps normal users quiet by default; enables “diagnostic mode” for builders/support.

⚠️ Compatibility
- Fully backwards compatible with firmware payloads:
  - Works with `{event:N}` only
  - Works with `{event, seq, deviceId, ...}`

---

## v5.0 (Device Status + Offline Detection)
✅ **Offline detection**
- Tracks last event timestamp.
- Sets `device_connected=false` if no events arrive within an **offline timeout** (default ~30s).
- Flips back to online automatically on next event.

✅ **Single-line status variable**
- Adds/maintains `device_status_text` (e.g. `CONNECTED | RSSI -55 | 12s ago`, or `OFFLINE`).

✅ **More “appliance-grade” status variables**
- Consistently updates `device_id`, `device_ip`, `device_last_seen`, `device_rssi`, `device_connected`.

🔁 **Minimal setup focus**
- Works out-of-box with defaults (listen port 8787).
- Display/TFT settings remain optional.

⚠️ Compatibility
- Does not require firmware changes.
- Still supports legacy devices and legacy plugins (depending on mode selection on device).

---

## v4.0 (Separate Key Label Pages: Short vs Long)
✅ **Two independent key label maps**
- Adds **Key labels (Short 0–35)** and **Key labels (Long 0–35)** as separate settings.
- `key_label` is selected from the correct list based on `kind` (short vs long).

⚠️ Compatibility
- Keeps compatibility with older single `keyLabels` field as fallback:
  - If short/long lists are empty, the plugin can still use the legacy list for both.

🛠 UX improvement
- Makes “short vs long press” feel like two separate control layers, matching real stream-deck behavior.

---

## v3.0 (Onboarding + Device Vars + Key Labels)
✅ **Professional onboarding / minimal setup**
- Defaults designed to “just work”:
  - Listener enabled by default
  - Default port 8787
- Advanced fields hidden behind “Show advanced settings” (where supported).

✅ **Device status variables (baseline set)**
- Tracks device presence on events and writes to Lumia variables:
  - `device_id`, `device_ip`, `device_last_seen`, `device_rssi`, `device_connected`
  - `seq`, `held_ms` (when present)

✅ **Key label mapping (single list)**
- Adds `Key labels (0–35)` setting (one label per line).
- Adds variable `key_label` and includes it in `extraSettings` for use in templates/alerts.

✅ **Reliability improvements retained**
- Continues v2 behavior: seq ACK support + dedupe.

⚠️ Compatibility
- Works with legacy `{event:N}`.
- Works with newer payloads containing `seq/deviceId`.

---

## v2.0 (Seq ACK + /health + Dedupe)
✅ **/health endpoint on plugin**
- Adds `GET /health` to confirm the plugin listener is up.

✅ **Seq ACK support**
- On `POST /event`, replies with JSON:
  - `{ ok: true, seq: <echo> }` when `seq` is provided.
- Enables confirmed mode on device firmware.

✅ **Dedupe / retry safety**
- Dedupes repeated events using `(deviceId, seq)` when available.
- Prevents double-triggering if the ESP retries.

⚠️ Compatibility
- Still accepts legacy `{event:N}` payloads.
- If `seq` is missing, plugin behaves like v1 but with safer response handling.

---

## v1.0 (Initial Integrated Plugin)
✅ **First combined plugin**
- Single plugin that:
  - Listens for ESP events at `POST /event`
  - Triggers two alerts (short + long), each with 36 key variations
  - Provides TFT actions:
    - Display Message (to `/msg` or `/ui` depending on mode)
    - Status Message (to `/status` or `/ui`)
    - Clear Screen (to `/clear` or `/ui`)

✅ **Legacy display compatibility**
- Supports “Legacy GET” endpoints for TFT:
  - `/msg`, `/status`, `/clear`
- Optional support for `POST /ui` for future UI expansion.

⚠️ Compatibility
- Designed to work with the original ESP event scheme:
  - `event: 0..35` = short press
  - `event: 36..71` = long press (key + 36)

---

# “Between Versions” Summary (What changed each step)

- **v1 → v2**
  - Added `/health`, seq ACK response, and dedupe so confirmed delivery is possible and retries don’t double-trigger.

- **v2 → v3**
  - Made it feel like a real product: minimal setup defaults, device status variables, and key labels (single list).

- **v3 → v4**
  - Split key labels into two independent maps: short and long press layers (more “stream deck” feel).

- **v4 → v5**
  - Added offline detection + a single `device_status_text` variable for clean overlays/support.

- **v5 → v5.1**
  - Added optional debug toasts (connect/offline, and optionally per-event/actions) with throttling.

---

# Appendix — Firmware Milestones (Optional Reference)

## Firmware v0.0.1 (Baseline integrated)
- WiFiManager provisioning
- TFT endpoints: `/msg`, `/status`, `/clear`, optional `/ui`
- Pico UART events → POST `/event`

## Firmware v0.0.2 (Self-test + /health + deviceId + seq)
- Added `/health` on device
- Added `deviceId` + `seq` in POST payload
- Added basic boot feedback (WiFi ok, etc.)

## Firmware v0.0.3 (Mode select + Confirmed/Legacy + TFT ACK feedback)
- On boot: wait for Pico matrix choice:
  - Key 1 = Legacy
  - Key 2 = Confirmed (requires seq ACK)
- Added TFT transient status:
  - `ACK OK` / `ACK FAIL`
- Header improved to keep IP visible while showing prompts/messages
- LED press-tick added for Pico diagnostics

---

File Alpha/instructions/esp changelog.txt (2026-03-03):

# Firmware Changelog — Lumi-Con ESP8266 (v1 → v4)

This tracks the ESP8266 firmware evolution as you’re defining it:

- **v1** = `lumi_con_esp_integrated_0_0_1.ino` (baseline integrated)
- **v2** = `lumi_con_esp_integrated_0_0_2.ino` (support/self-test + /health + seq payload)
- **v3** = `lumi_con_esp_integrated_0_0_3.ino` (mode select + confirmed/legacy + TFT ACK feedback)
- **v4** = `lumi_con_esp_integrated_0_0_4.ino` (performance: partial redraws)

---

## v4 (Performance Update: Partial Redraw)
**Key features**
- **Faster display updates** by switching from full-screen redraws to **partial redraws**:
  - Header Line 1 redraws only when transient/prompt changes or expires
  - Header Line 2 redraws only when status/last-key changes
  - Chat area redraws only when chat content changes (new message / clear)
- **Same visible UI / same behaviour** (text content, layout, endpoints, prompts, ACK messages unchanged)
- Reduces flicker and SPI traffic, improving responsiveness

**Compatibility**
- Endpoints unchanged:
  - `/msg`, `/status`, `/clear`, `/ui`, `/health`
- Pico UART protocol unchanged
- Works with existing Lumia plugin versions the same as v3

---

## v3 (Mode Select + Confirm/Legacy + Pro TFT Feedback)
**Key features**
- **Boot mode selection via Pico matrix** (no ESP GPIO buttons required):
  - Key **1** = **LEGACY** mode (works with old plugins; treats HTTP 2xx as success)
  - Key **2** = **CONFIRMED** mode (requires `{ ok:true, seq:<same> }` ACK)
  - ESP **waits until a choice is made** (no auto mode)
- **Professional TFT feedback**
  - Two-line header:
    - Line 1: prompts + transient messages
    - Line 2: IP + last key pressed
  - Shows transient results like **ACK OK** / **ACK FAIL**
  - Transient expiry redraw (message clears cleanly)
- **Diagnostics**
  - LED “press tick” on every PRESS packet (verifies Pico/UART is alive)
  - Keeps success/failure blink patterns on event send

**Compatibility**
- Fully compatible with v2/v1 endpoints:
  - `/msg`, `/status`, `/clear`, `/ui`, `/health`
- Works with old plugins in LEGACY mode
- Best reliability with new plugins in CONFIRMED mode

---

## v2 (Self-Test + /health + deviceId + seq payload)
**Key features**
- **Self-test / startup visibility**
  - TFT displays **IP** after WiFi connect
  - TFT updates with **last key pressed** (K:##S / K:##L)
- **Support endpoints**
  - Adds `GET /health` on ESP returning JSON:
    - `deviceId`, `ip`, `rssi`, `uptimeMs`, `lastKey`, `lastSeq`, `lastAck`, `lastPostOk`
- **Richer event payload (backwards compatible)**
  - Still sends `{"event":N}` semantics
  - Adds optional fields: `seq`, `deviceId`, `key`, `press`, `heldMs`, `uptimeMs`, `rssi`
- **LED diagnostics**
  - WiFi OK: **2 quick blinks**
  - PC reachable (plugin `/health`): **3 quick blinks**
  - PC unreachable: **3 slow blinks**
  - Pico detected (first valid UART packet): **1 quick blink**
- **Factory reset**
  - Hold **Key 0** at boot to wipe WiFiManager credentials and restart

**Compatibility**
- Endpoints unchanged from v1 plus new `/health`
- Event format remains compatible with old plugins (they ignore extra JSON fields)

---

## v1 (Baseline Integrated Firmware)
**Key features**
- WiFi connect (either hardcoded or early WiFiManager baseline depending on your initial file)
- TFT message endpoints:
  - `GET /msg?t=...`
  - `GET /clear`
  - (and in later baseline builds: `/status`, `/ui`)
- Reads Pico UART packets (`A5 type key xor`)
- Sends key events to Lumia plugin:
  - `POST /event` with `{"event":0..71}` (short/long encoding)

**Compatibility**
- Established the core “contract” that remains stable through later versions:
  - Pico → ESP UART unchanged
  - ESP → plugin `/event` unchanged
  - Display endpoints retained

---

# Upgrade Summary
- **v1 → v2:** added self-test, `/health`, richer event payload, factory reset, and startup diagnostics
- **v2 → v3:** added user-selected reliability mode (legacy vs confirmed) and professional TFT feedback (ACK OK/FAIL + two-line header)
- **v3 → v4:** improved performance by switching from full-screen redraws to partial redraws (header/chat redraw only when changed)

---

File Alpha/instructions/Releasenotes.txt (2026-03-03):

# Release Notes — Lumi-Con Integrated Plugin (v1 → v5.2 feature highlights)

Short, user-facing notes you can paste into GitHub Releases, README highlights, or YouTube descriptions.

---

## v5.2 — Maintenance Release
- Includes all v5.1 features.
- v5.2 is typically a packaging/ID/docs tidy-up release.

---

## v5.1 — Optional Debug Toasts (Feature Highlight)
- Added **optional debug toasts** inside Lumia (default OFF).
- Toast modes:
  - **Important**: toasts only on **Connected** and **Offline**
  - **Verbose**: toasts on **Connected/Offline** + **every key event** + **every TFT action**
- Includes basic **rate limiting** so it won’t spam too hard.

Best for: troubleshooting, builder support, quick verification during setup.

---

## v5.0 — Device Status + Offline Detection
- Added **offline detection** (no events for ~30s → device marked offline).
- Added `device_status_text` variable (single-line “device health” string).
- Keeps device status variables up-to-date automatically.

Best for: “professional feel” + easy overlays (“connected/offline”) + support.

---

## v4.0 — Separate Key Label Pages (Short vs Long)
- Added **two independent key label maps**:
  - **Key labels (Short 0–35)**
  - **Key labels (Long 0–35)**
- `key_label` automatically matches the press type (short/long).

Best for: real stream-deck behavior (two layers) without confusion.

---

## v3.0 — Onboarding + Key Labels + Device Vars
- Improved **out-of-box experience** (sane defaults, minimal required setup).
- Added **key labels (0–35)** mapping and `key_label` variable.
- Added baseline **device status variables** (id, last seen, rssi, connected, etc.).

Best for: users who want a cleaner “product” experience.

---

## v2.0 — Confirmed Delivery (Seq ACK + /health + Dedupe)
- Added `GET /health` endpoint on the plugin listener.
- Added **seq ACK** response for `/event` so “confirmed mode” works reliably.
- Added **dedupe** using `(deviceId, seq)` to prevent double triggers during retries.

Best for: reliability and “appliance grade” behavior.

---

## v1.0 — First Integrated Release
- Combined **matrix event listener** + **TFT display actions** into one plugin.
- Two alerts (Short + Long) with **36 variations each**.
- Display actions for TFT:
  - Display Message, Status Message, Clear Screen
- Supports both display modes:
  - **Legacy GET** (`/msg`, `/status`, `/clear`)
  - **UI POST** (`/ui` JSON)

Best for: getting the full stack working quickly.

---

# Upgrade Summary (One-liners)
- **v1 → v2:** reliability foundation (health + ack + dedupe)
- **v2 → v3:** onboarding + labels + device status variables
- **v3 → v4:** short/long label maps split cleanly
- **v4 → v5:** offline detection + single status string for overlays
- **v5 → v5.1:** optional Lumia toasts for debugging/support

---

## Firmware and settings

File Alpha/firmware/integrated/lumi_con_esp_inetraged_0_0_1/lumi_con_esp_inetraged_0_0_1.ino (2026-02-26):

/*
  Lumi-Con ESP8266 firmware v0.0.1 (integrated)
  -------------------------------------
  - TFT display (ST7735 1.8" 128x160)
  - Receives display text via HTTP:
      GET  /msg?t=Hello%20world      -> chat/log area (wrapped, scrolling)
      GET  /status?t=OK%3A%20Done    -> status/confirm line (top line)
      GET  /clear                   -> clears screen/buffers
      POST /ui  {"channel":"chat|status|clear","text":"..."}  -> future UI hook

  - Receives key press/release packets from Pico over UART (ESP Serial RX):
      Packet: A5, type(1 press / 0 release), key(0..35), xor

  - Computes short/long press and sends to Lumia plugin:
      POST http://PLUGIN_HOST:PLUGIN_PORT/event
      Body: {"event": N}   where:
        short press: 0..35
        long press:  36..71  (key + 36)

  Notes:
  - WiFiManager is used, but Serial output is disabled to avoid corrupting UART RX.
  - Firmware is future-ready: status line reserved, /ui JSON endpoint included.
*/

#include <Arduino.h>
#include <ESP8266WiFi.h>
#include <ESP8266WebServer.h>
#include <WiFiManager.h>
#include <ESP8266HTTPClient.h>
#include <WiFiClient.h>

#include <Adafruit_GFX.h>
#include <Adafruit_ST7735.h>
#include <SPI.h>

// ===================== CONFIG =====================

// ---- Lumia plugin endpoint (PC running Lumia) ----
const char* PLUGIN_HOST = "192.168.1.87";
constexpr uint16_t PLUGIN_PORT = 8787;

// Optional shared secret (must match plugin setting), leave "" to disable
const char* PLUGIN_SECRET = "";

// ---- Pico UART ----
constexpr uint32_t PICO_BAUD = 115200;
constexpr uint8_t KEY_COUNT = 36;
constexpr uint32_t LONG_PRESS_MS = 600;

// ---- TFT pins (keep your existing wiring) ----
#define TFT_CS   D2
#define TFT_DC   D1
#define TFT_RST  D0   // If you hit white-screen issues, see notes at bottom.

Adafruit_ST7735 tft = Adafruit_ST7735(TFT_CS, TFT_DC, TFT_RST);

// For many 1.8" ST7735 128x160 modules:
// INITR_GREENTAB / INITR_REDTAB / INITR_BLACKTAB
#define ST7735_TAB INITR_GREENTAB

// ---- Screen geometry ----
static const uint16_t BG = ST77XX_BLACK;
static const uint16_t FG = ST77XX_WHITE;

static const int SCREEN_W = 160;
static const int SCREEN_H = 128;

static const int CHAR_W = 6;  // default font 5+1
static const int LINE_H = 8;
static const int MAX_COLS = SCREEN_W / CHAR_W;   // ~26 for 160/6
static const int MAX_LINES = SCREEN_H / LINE_H;  // 16 for 128/8

// Reserve 1 line for status (future screen partition hook)
static const int STATUS_LINES = 1;
static const int CHAT_LINES = MAX_LINES - STATUS_LINES;

// ===================== GLOBALS =====================

ESP8266WebServer server(80);

// Chat ring buffer
String chatBuf[CHAT_LINES];
int chatCount = 0;

// Status line
String statusLine = "";

// Key press tracking for long press calc (ESP-side)
uint32_t pressStart[KEY_COUNT] = {};
bool isDown[KEY_COUNT] = {};

// ===================== UTILITIES =====================

static inline String trimRightSpaces(String s) {
  while (s.endsWith(" ")) s.remove(s.length() - 1);
  return s;
}

String urlDecode(const String& in) {
  String out;
  out.reserve(in.length());
  for (size_t i = 0; i < in.length(); i++) {
    char c = in[i];
    if (c == '+') {
      out += ' ';
    } else if (c == '%' && i + 2 < in.length()) {
      char h1 = in[i + 1];
      char h2 = in[i + 2];
      auto hexVal = [](char h) -> int {
        if (h >= '0' && h <= '9') return h - '0';
        if (h >= 'a' && h <= 'f') return 10 + (h - 'a');
        if (h >= 'A' && h <= 'F') return 10 + (h - 'A');
        return 0;
      };
      char decoded = (hexVal(h1) << 4) | hexVal(h2);
      out += decoded;
      i += 2;
    } else {
      out += c;
    }
  }
  return out;
}

String truncateToCols(const String& s, int cols) {
  if ((int)s.length() <= cols) return s;
  return s.substring(0, cols);
}

// ===================== TFT RENDERING =====================

void addChatLine(const String& line) {
  if (chatCount < CHAT_LINES) {
    chatBuf[chatCount++] = line;
  } else {
    // shift up
    for (int i = 1; i < CHAT_LINES; i++) chatBuf[i - 1] = chatBuf[i];
    chatBuf[CHAT_LINES - 1] = line;
  }
}

void redrawScreen() {
  tft.fillScreen(BG);
  tft.setTextWrap(false);
  tft.setTextSize(1);
  tft.setTextColor(FG, BG);

  int y = 0;

  // Status line (top line)
  String st = truncateToCols(statusLine, MAX_COLS);
  if (st.length()) {
    tft.setCursor(0, y);
    tft.print(st);
  }
  y += LINE_H * STATUS_LINES;

  // Chat area bottom-aligned within remaining space (like your original)
  int visible = CHAT_LINES;
  int startIndex = (chatCount > visible) ? (chatCount - visible) : 0;

  // Compute where to start so it's bottom-up within the chat region
  int linesToDraw = chatCount - startIndex;
  int chatRegionH = (MAX_LINES - STATUS_LINES) * LINE_H;
  int yStart = (STATUS_LINES * LINE_H) + (chatRegionH - linesToDraw * LINE_H);
  if (yStart < STATUS_LINES * LINE_H) yStart = STATUS_LINES * LINE_H;

  int yy = yStart;
  for (int i = startIndex; i < chatCount; i++) {
    tft.setCursor(0, yy);
    tft.print(truncateToCols(chatBuf[i], MAX_COLS));
    yy += LINE_H;
    if (yy >= SCREEN_H) break;
  }
}

// Wrap + add to chat buffer (your original behavior)
void pushWrappedChat(const String& msgRaw) {
  String msg = msgRaw;
  msg.replace("\r", "");

  int start = 0;
  while (start <= (int)msg.length()) {
    int nl = msg.indexOf('\n', start);
    String segment = (nl == -1) ? msg.substring(start) : msg.substring(start, nl);
    segment = trimRightSpaces(segment);

    int idx = 0;
    while (idx < (int)segment.length()) {
      int remaining = segment.length() - idx;

      if (remaining <= MAX_COLS) {
        addChatLine(segment.substring(idx));
        idx = segment.length();
        break;
      }

      int cut = idx + MAX_COLS;
      int space = segment.lastIndexOf(' ', cut);
      if (space <= idx) {
        addChatLine(segment.substring(idx, idx + MAX_COLS));
        idx += MAX_COLS;
      } else {
        addChatLine(segment.substring(idx, space));
        idx = space + 1;
      }
    }

    if (nl == -1) break;
    start = nl + 1;
  }

  redrawScreen();
}

void clearAll() {
  chatCount = 0;
  statusLine = "";
  tft.fillScreen(BG);
}

// ===================== HTTP HANDLERS =====================

void handleRoot() {
  String page =
    "Lumi-Con ESP OK\n\n"
    "Chat/log:\n"
    "  /msg?t=Hello%20world\n\n"
    "Status:\n"
    "  /status?t=OK%3A%20Lights%20On\n\n"
    "Clear:\n"
    "  /clear\n\n"
    "Future UI:\n"
    "  POST /ui {\"channel\":\"chat|status|clear\",\"text\":\"...\"}\n";
  server.send(200, "text/plain", page);
}

void handleMsg() {
  if (!server.hasArg("t")) {
    server.send(400, "text/plain", "Missing query param 't'");
    return;
  }
  String text = urlDecode(server.arg("t"));
  if (!text.length()) {
    server.send(400, "text/plain", "Empty message");
    return;
  }
  pushWrappedChat(text);
  server.send(200, "text/plain", "OK");
}

void handleStatus() {
  if (!server.hasArg("t")) {
    server.send(400, "text/plain", "Missing query param 't'");
    return;
  }
  String text = urlDecode(server.arg("t"));
  statusLine = text;
  redrawScreen();
  server.send(200, "text/plain", "OK");
}

void handleClear() {
  clearAll();
  server.send(200, "text/plain", "CLEARED");
}

// Minimal JSON extraction without adding heavy libs
// Expects: {"channel":"chat|status|clear","text":"..."}
String jsonFindString(const String& body, const String& key) {
  int k = body.indexOf("\"" + key + "\"");
  if (k < 0) return "";
  int colon = body.indexOf(':', k);
  if (colon < 0) return "";
  int q1 = body.indexOf('"', colon + 1);
  if (q1 < 0) return "";
  int q2 = body.indexOf('"', q1 + 1);
  if (q2 < 0) return "";
  return body.substring(q1 + 1, q2);
}

void handleUi() {
  if (server.method() != HTTP_POST) {
    server.send(405, "text/plain", "POST only");
    return;
  }

  String body = server.arg("plain");
  body.trim();
  if (!body.length()) {
    server.send(400, "text/plain", "Empty body");
    return;
  }

  String channel = jsonFindString(body, "channel");
  String text = jsonFindString(body, "text");

  if (channel == "clear") {
    clearAll();
    server.send(200, "text/plain", "OK");
    return;
  }

  if (!text.length()) {
    server.send(400, "text/plain", "Missing text");
    return;
  }

  if (channel == "status") {
    statusLine = text;
    redrawScreen();
  } else {
    // default to chat
    pushWrappedChat(text);
  }

  server.send(200, "text/plain", "OK");
}

// ===================== PICO UART PACKET DECODE =====================

bool readPicoPacket(uint8_t &type, uint8_t &key) {
  static uint8_t state = 0;
  static uint8_t b1 = 0, b2 = 0;

  while (Serial.available()) {
    uint8_t b = (uint8_t)Serial.read();
    switch (state) {
      case 0: if (b == 0xA5) state = 1; break;
      case 1: b1 = b; state = 2; break;
      case 2: b2 = b; state = 3; break;
      case 3: {
        uint8_t chk = (uint8_t)(0xA5 ^ b1 ^ b2);
        state = 0;
        if (b == chk) { type = b1; key = b2; return true; }
        break;
      }
    }
  }
  return false;
}

// ===================== POST EVENT TO PLUGIN =====================

bool postEventToPlugin(uint8_t eventNumber) {
  if (WiFi.status() != WL_CONNECTED) return false;

  WiFiClient client;
  HTTPClient http;

  String url = String("http://") + PLUGIN_HOST + ":" + String(PLUGIN_PORT) + "/event";
  String body = String("{\"event\":") + String(eventNumber) + "}";

  uint32_t backoff = 200;
  for (uint8_t attempt = 1; attempt <= 3; attempt++) {
    http.setTimeout(1200);

    if (!http.begin(client, url)) {
      http.end();
      delay(backoff);
      backoff *= 2;
      continue;
    }

    http.addHeader("Content-Type", "application/json");
    if (PLUGIN_SECRET && PLUGIN_SECRET[0] != '\0') {
      http.addHeader("X-Matrix-Secret", PLUGIN_SECRET);
    }

    int code = http.POST((uint8_t*)body.c_str(), body.length());
    http.end();

    if (code >= 200 && code < 300) return true;

    delay(backoff);
    backoff *= 2;
    yield();
  }

  return false;
}

// ===================== SETUP / LOOP =====================

void showBootLine(const String& s) {
  statusLine = s;
  redrawScreen();
}

void setup() {
  // IMPORTANT: Serial RX is used for Pico packets. Avoid Serial prints entirely.
  Serial.begin(PICO_BAUD);
  Serial.setDebugOutput(false);
  delay(150);

  // TFT init (do this early)
  SPI.begin(); // safe explicit init
  tft.initR(ST7735_TAB);
  tft.setRotation(1);
  tft.fillScreen(BG);
  tft.setTextColor(FG, BG);
  tft.setTextSize(1);

  showBootLine("WiFi setup...");

  // WiFiManager (NO DEBUG OUTPUT to Serial!)
  WiFiManager wm;
  wm.setDebugOutput(false);
  wm.setConfigPortalTimeout(180);

  // Optional: show AP name if config portal starts
  wm.setAPCallback([](WiFiManager *wmp) {
    (void)wmp;
    // Can't capture safely here; keep minimal.
  });

  bool ok = wm.autoConnect("Lumi-Con-Setup");
  (void)ok;

  showBootLine("IP: " + WiFi.localIP().toString());

  // HTTP routes
  server.on("/", handleRoot);
  server.on("/msg", HTTP_GET, handleMsg);
  server.on("/status", HTTP_GET, handleStatus);
  server.on("/clear", HTTP_GET, handleClear);
  server.on("/ui", HTTP_POST, handleUi);
  server.begin();

  pinMode(LED_BUILTIN, OUTPUT);
  digitalWrite(LED_BUILTIN, HIGH);
}

void loop() {
  server.handleClient();

  // Pico UART -> short/long -> plugin
  uint8_t type, key;
  if (readPicoPacket(type, key)) {
    if (key >= KEY_COUNT) return;

    uint32_t now = millis();

    if (type == 1) {
      // PRESS
      if (!isDown[key]) {
        isDown[key] = true;
        pressStart[key] = now;
      }
    } else {
      // RELEASE
      if (isDown[key]) {
        isDown[key] = false;

        uint32_t held = now - pressStart[key];
        uint8_t eventOut = (held >= LONG_PRESS_MS) ? (uint8_t)(key + 36) : key;

        bool okSend = postEventToPlugin(eventOut);

        // Tiny LED feedback only (no Serial)
        if (okSend) {
          digitalWrite(LED_BUILTIN, LOW); delay(30);
          digitalWrite(LED_BUILTIN, HIGH);
        } else {
          for (int i = 0; i < 2; i++) {
            digitalWrite(LED_BUILTIN, LOW); delay(30);
            digitalWrite(LED_BUILTIN, HIGH); delay(60);
          }
        }
      }
    }
  }

  yield();
}

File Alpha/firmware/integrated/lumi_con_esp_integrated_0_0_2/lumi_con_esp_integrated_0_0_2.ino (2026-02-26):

/*
  Lumi-Con ESP8266 firmware v0.0.2  (between your v0.0.1 and v0.0.3)
  ------------------------------------------------------------------
  Adds:
  - /health endpoint on ESP
  - deviceId + seq + extra telemetry in POST /event payload (backwards compatible)
  - Self-test:
      - TFT shows IP + last key pressed
      - LED blink codes:
          WiFi OK: 2 quick
          PC reachable (/health on plugin): 3 quick
          PC unreachable: 3 slow
          Pico detected (first UART packet): 1 quick
  - Factory reset: hold Key 0 during boot to wipe WiFiManager credentials

  Keeps:
  - TFT endpoints: /msg /status /clear /ui
  - Pico UART protocol: A5 type key xor
  - Event mapping: short=0..35, long=36..71
*/

#include <Arduino.h>
#include <ESP8266WiFi.h>
#include <ESP8266WebServer.h>
#include <WiFiManager.h>
#include <ESP8266HTTPClient.h>
#include <WiFiClient.h>

#include <Adafruit_GFX.h>
#include <Adafruit_ST7735.h>
#include <SPI.h>

// ===================== CONFIG =====================

// ---- Lumia plugin endpoint (your PC) ----
const char* PLUGIN_HOST = "192.168.1.87";
constexpr uint16_t PLUGIN_PORT = 8787;
const char* PLUGIN_SECRET = ""; // optional header X-Matrix-Secret

// ---- Pico UART ----
constexpr uint32_t PICO_BAUD = 115200;
constexpr uint8_t KEY_COUNT = 36;
constexpr uint32_t LONG_PRESS_MS = 600;

// ---- Factory reset (hold this key on boot) ----
constexpr uint8_t FACTORY_RESET_KEY = 0;
constexpr uint32_t FACTORY_RESET_HOLD_MS = 1200;
constexpr uint32_t FACTORY_RESET_WINDOW_MS = 2500;

// ---- TFT pins ----
#define TFT_CS   D2
#define TFT_DC   D1
#define TFT_RST  D0
Adafruit_ST7735 tft = Adafruit_ST7735(TFT_CS, TFT_DC, TFT_RST);
#define ST7735_TAB INITR_GREENTAB

// ---- Screen layout ----
static const uint16_t BG = ST77XX_BLACK;
static const uint16_t FG = ST77XX_WHITE;

static const int SCREEN_W = 160;
static const int SCREEN_H = 128;

static const int CHAR_W = 6;
static const int LINE_H = 8;
static const int MAX_COLS = SCREEN_W / CHAR_W;
static const int MAX_LINES = SCREEN_H / LINE_H;

static const int STATUS_LINES = 1;
static const int CHAT_LINES = MAX_LINES - STATUS_LINES;

// ===================== GLOBALS =====================

ESP8266WebServer server(80);

// Device identity
String deviceId;

// Chat buffer
String chatBuf[CHAT_LINES];
int chatCount = 0;

// Status line
String statusBase = "";      // e.g. "IP:192.168.1.50"
String lastKeyText = "K:--"; // e.g. "K:12L"

// Key press tracking
uint32_t pressStart[KEY_COUNT] = {};
bool isDown[KEY_COUNT] = {};

// Pico detected flag
bool picoSeen = false;

// Sequence counter + last result
uint32_t seqCounter = 0;
uint32_t lastSeqSent = 0;
uint32_t lastAckSeq = 0;
bool lastPostOk = false;

// ===================== LED HELPERS (active-low LED) =====================

void ledOn()  { digitalWrite(LED_BUILTIN, LOW); }
void ledOff() { digitalWrite(LED_BUILTIN, HIGH); }

void blink(uint8_t times, uint16_t onMs, uint16_t offMs) {
  for (uint8_t i = 0; i < times; i++) {
    ledOn();  delay(onMs);
    ledOff(); delay(offMs);
    yield();
  }
}

// ===================== TFT HELPERS =====================

String truncateCols(const String& s) {
  if ((int)s.length() <= MAX_COLS) return s;
  return s.substring(0, MAX_COLS);
}

void addChatLine(const String& line) {
  if (chatCount < CHAT_LINES) {
    chatBuf[chatCount++] = line;
  } else {
    for (int i = 1; i < CHAT_LINES; i++) chatBuf[i - 1] = chatBuf[i];
    chatBuf[CHAT_LINES - 1] = line;
  }
}

void redrawScreen() {
  tft.fillScreen(BG);
  tft.setTextWrap(false);
  tft.setTextSize(1);
  tft.setTextColor(FG, BG);

  // Status (single line): "<statusBase> <lastKeyText>"
  String s = statusBase;
  if (s.length()) s += " ";
  s += lastKeyText;
  s = truncateCols(s);

  tft.setCursor(0, 0);
  tft.print(s);

  // Chat area (bottom aligned)
  int startIndex = (chatCount > CHAT_LINES) ? (chatCount - CHAT_LINES) : 0;
  int linesToDraw = chatCount - startIndex;

  int chatRegionH = CHAT_LINES * LINE_H;
  int yStart = (STATUS_LINES * LINE_H) + (chatRegionH - linesToDraw * LINE_H);
  if (yStart < STATUS_LINES * LINE_H) yStart = STATUS_LINES * LINE_H;

  int y = yStart;
  for (int i = startIndex; i < chatCount; i++) {
    tft.setCursor(0, y);
    tft.print(truncateCols(chatBuf[i]));
    y += LINE_H;
    if (y >= SCREEN_H) break;
  }
}

String urlDecode(const String& in) {
  String out;
  out.reserve(in.length());
  for (size_t i = 0; i < in.length(); i++) {
    char c = in[i];
    if (c == '+') out += ' ';
    else if (c == '%' && i + 2 < in.length()) {
      auto hexVal = [](char h) -> int {
        if (h >= '0' && h <= '9') return h - '0';
        if (h >= 'a' && h <= 'f') return 10 + (h - 'a');
        if (h >= 'A' && h <= 'F') return 10 + (h - 'A');
        return 0;
      };
      char decoded = (hexVal(in[i + 1]) << 4) | hexVal(in[i + 2]);
      out += decoded;
      i += 2;
    } else out += c;
  }
  return out;
}

void clearAll() {
  chatCount = 0;
  statusBase = "";
  lastKeyText = "K:--";
  tft.fillScreen(BG);
}

void pushWrappedChat(const String& msgRaw) {
  String msg = msgRaw;
  msg.replace("\r", "");

  int start = 0;
  while (start <= (int)msg.length()) {
    int nl = msg.indexOf('\n', start);
    String segment = (nl == -1) ? msg.substring(start) : msg.substring(start, nl);

    while (segment.endsWith(" ")) segment.remove(segment.length() - 1);

    int idx = 0;
    while (idx < (int)segment.length()) {
      int remaining = segment.length() - idx;

      if (remaining <= MAX_COLS) {
        addChatLine(segment.substring(idx));
        idx = segment.length();
        break;
      }

      int cut = idx + MAX_COLS;
      int space = segment.lastIndexOf(' ', cut);
      if (space <= idx) {
        addChatLine(segment.substring(idx, idx + MAX_COLS));
        idx += MAX_COLS;
      } else {
        addChatLine(segment.substring(idx, space));
        idx = space + 1;
      }
    }

    if (nl == -1) break;
    start = nl + 1;
  }

  redrawScreen();
}

// ===================== HTTP HANDLERS =====================

void handleRoot() {
  server.send(200, "text/plain",
    "Lumi-Con ESP OK\n"
    "GET /msg?t=Hello\n"
    "GET /status?t=OK\n"
    "GET /clear\n"
    "POST /ui {\"channel\":\"chat|status|clear\",\"text\":\"...\"}\n"
    "GET /health\n"
  );
}

void handleMsg() {
  if (!server.hasArg("t")) return server.send(400, "text/plain", "Missing 't'");
  String text = urlDecode(server.arg("t"));
  if (!text.length()) return server.send(400, "text/plain", "Empty");
  pushWrappedChat(text);
  server.send(200, "text/plain", "OK");
}

void handleStatus() {
  if (!server.hasArg("t")) return server.send(400, "text/plain", "Missing 't'");
  statusBase = urlDecode(server.arg("t"));
  redrawScreen();
  server.send(200, "text/plain", "OK");
}

void handleClear() {
  clearAll();
  server.send(200, "text/plain", "CLEARED");
}
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
